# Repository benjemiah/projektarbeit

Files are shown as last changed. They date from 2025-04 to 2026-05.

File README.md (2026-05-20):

# projektarbeit

Git-Repo für die Projektarbeit des 6. Semesters

## Struktur

- **pcb**: KiCad-Projektdateien für die Platine des Retro-Terminals
  - **Gerber**: Gerber-Files der Platine
  - **eigenes.pretty**: Nicht-Standard Footprints/ Schaltzeichen für Bauteile
- **code**: Arduino-Code für die Atmega328P's des Retro-Terminals
- **presentation**
  - **website**: Website zur Präsentation des Projektseminars

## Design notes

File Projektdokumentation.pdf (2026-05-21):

## Projektdokumentation „Retro Terminal“ Ein Atmega328 Aufbau zur Verarbeitung von PS/2 Inputs und Ausgabe über VGA

Ein Projekt von Jule Jäger, Natalie Weigand und Benjamin Blaga 15.05.2026

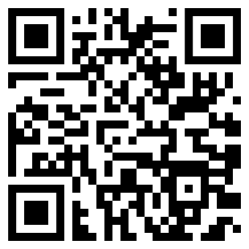
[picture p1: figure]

GitHub-Repo zum „Retro Terminal“

Ziel des Projekts:
Das Ziel des Projektes ist der Aufbau und die Inbetriebnahme einer eigens entworfenen Schaltung zum Einlesen, Auswerten und Ausgeben von PS/2 Inputs über VGA. Umgesetzt werden soll dies mithilfe von zwei ATmega328-P Mikrocontroller, vorgeladen mit dem Arduino Uno Bootloader. Dabei soll die Modularität für zukünftige Erweiterungen ermöglicht werden sowie ergänzende Funktionen wie z.B. ein Buzzer bereitgestellt werden.
Hauptfunktionen:
- Einlesen von Benutzerinput mithilfe einer Tastatur über den PS/2-Standard
- Ausgabe von eingelesenen Benutzerinput über monochromes VGA
- Ansteuerung eines Buzzers für akustische Funktionen
- Schaltungsaufbau ermöglicht einfaches Debugging bei Änderungsbedarf

Projektkomponenten:
- Platine
- Software

In dieser Dokumentation wird der Aufbau, die Systemkomponenten und die Inbetriebnahme erklärt.

## Platine

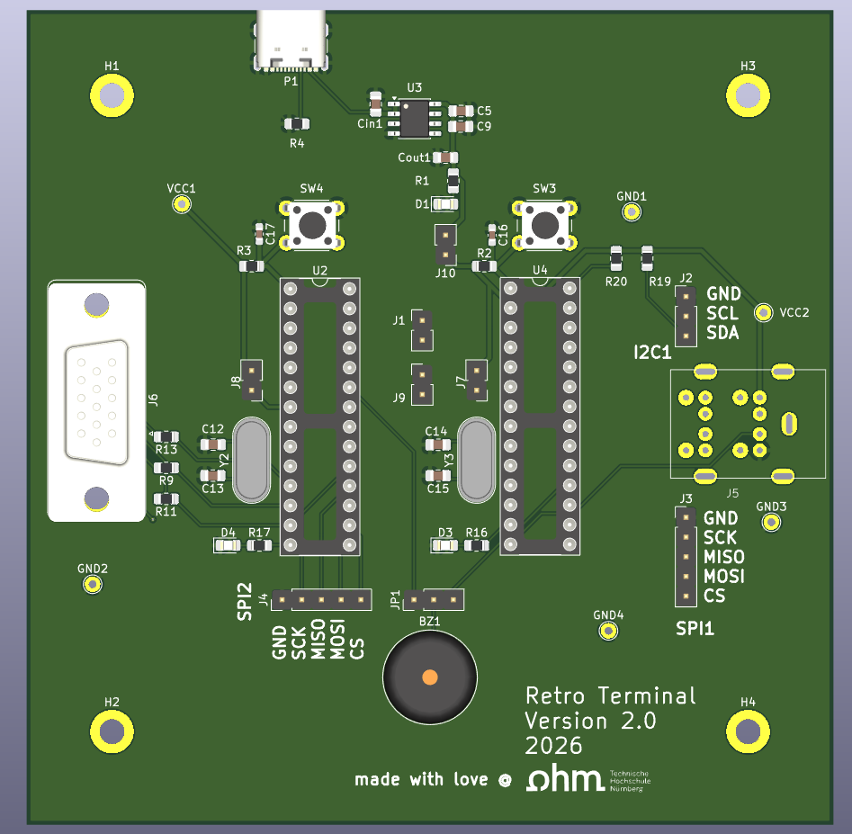
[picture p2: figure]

3D-Render der Platine, erstellt in KiCad (15.05.2026)
Stromversorgung

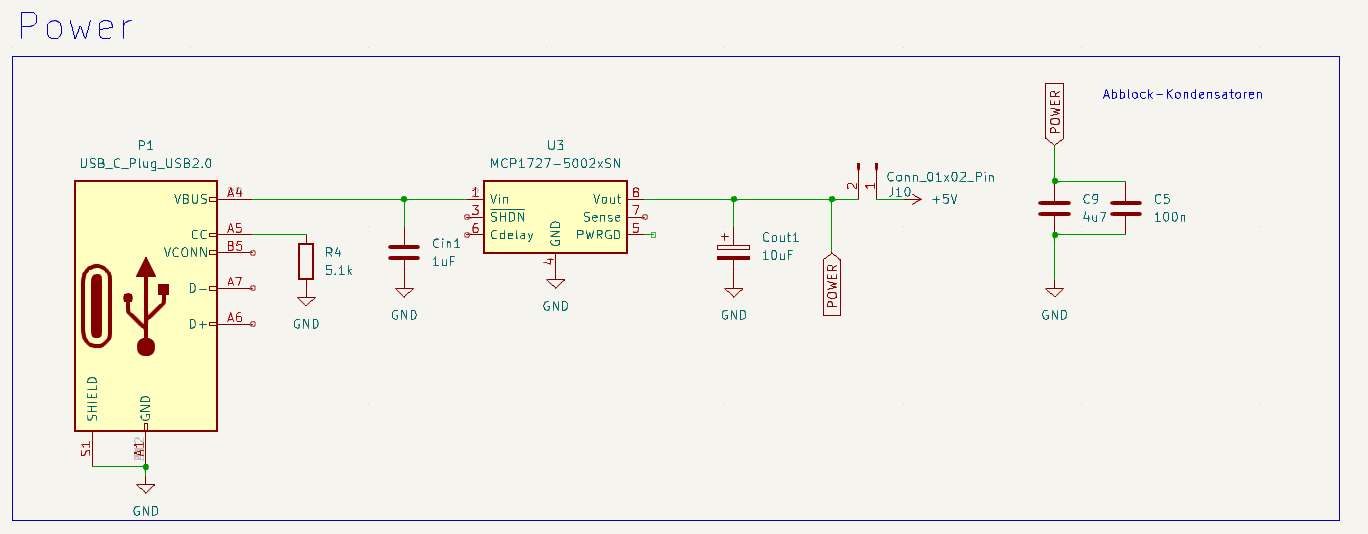
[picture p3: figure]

Die Platine wird versorgt mit einem USB-C Kabel über ein USB-C konformen Verbindungsstecker. Der Widerstand R4 vermittelt dem USB-C Host (Versorger) dass diese Platine ein Sink ist und Standard-USB-Spannung erwartet wird, in diesem Fall 5V. Weiterhin wird, um Überspannung zu verhindern ein LDO-Spannungsregler vom Typ MCP1727-5002 benutzt, um eine konstante Spannung von 5V zu garantieren sowie ein Maximalstrom von 1.5A. Zum Schutz der Mikrocontroller wurden Abblock-Kondensatoren platziert sowie Jumper-Pins, falls eine alternative Spannungsversorgung benötigt wird.

## Mikrocontroller

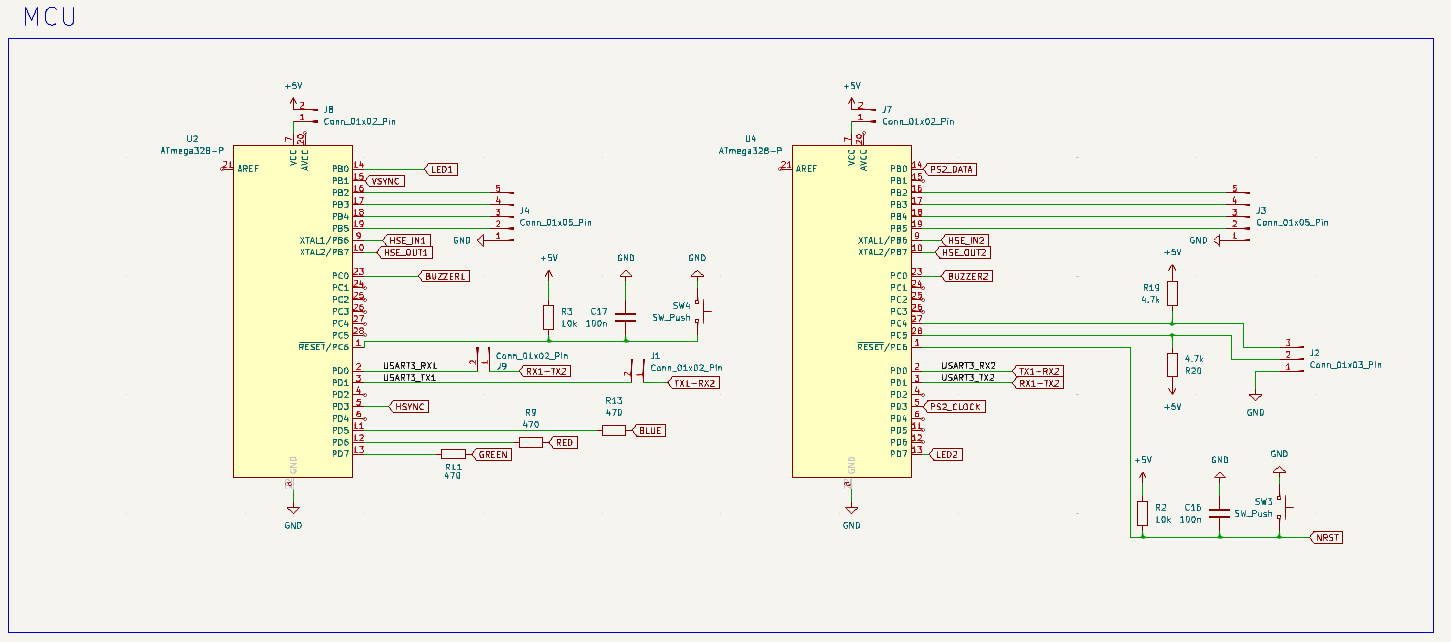
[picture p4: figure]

Die Platine utilisiert 2x Microchip ATmega328-P Mikrocontroller in der DIP-28 Bauform. Diese werden betrieben in einer Minimalausführung: Es werden lediglich Spannungsversorgung sowie Takt mithilfe von Standardquarzen (siehe unten) zugeführt. Um das Debugging zu erleichtern, haben die Mikrocontroller jeweils einzelne Reset-Knöpfe sowie Jumper-Pins zum optionalen Ausschalten der einzelnen Mikrocontroller.
Herausgeführt wurden die benötigten GPIO-Pins für die benötigten Funktionalitäten, namentlich:
- Verbindungen für VGA-Funktionalität (Pins gekennzeichnet mit „RED“, „GREEN“, „BLUE“, „VSYNC“, „HSYNC“)
- Verbindungen für PS/2-Funktionalität (Pins gekennzeichnet mit „PS2_CLOCK“, „PS2_DATA“)
- Verbindungen für die serielle Kommunikation zwischen den beiden ATmega328-P Mikrocontrollern (Pins gekennzeichnet mit „TX1-RX2“, „RX1-TX2“, „RX1-TX2“, „TX2-RX2“
- Verbindungen für Buzzer-Funktionalität (Pins gekennzeichnet mit „BUZZER1“, BUZZER2“)
- Verbindungen für serielle Schnittstellen für zukünftige Erweiterungen (Pins verbunden mit „J4“, „J3“ und „J2“
- Verbindungen für Status-LEDs (Pins gekennzeichnet mit „LED1“, „LED2“)

(Verbindungen zur allgemeinen Stromversorgung werden hier nicht berücksichtigt)

Es sind Jumper-Pins vorhanden um die bidirektionale Kommunikation über UART zwischen den Mikrocontrollern einzuschränken/ modifizieren zu können.
Beide Mikrocontroller sind in der Lage den Buzzer anzusteuern, falls benötigt.
„J2“ ist als I2C-Steckverbindung, „J3“ und „J4“ als SPI-Steckverbindungen vorgesehen.

## Diverse Systemkomponenten

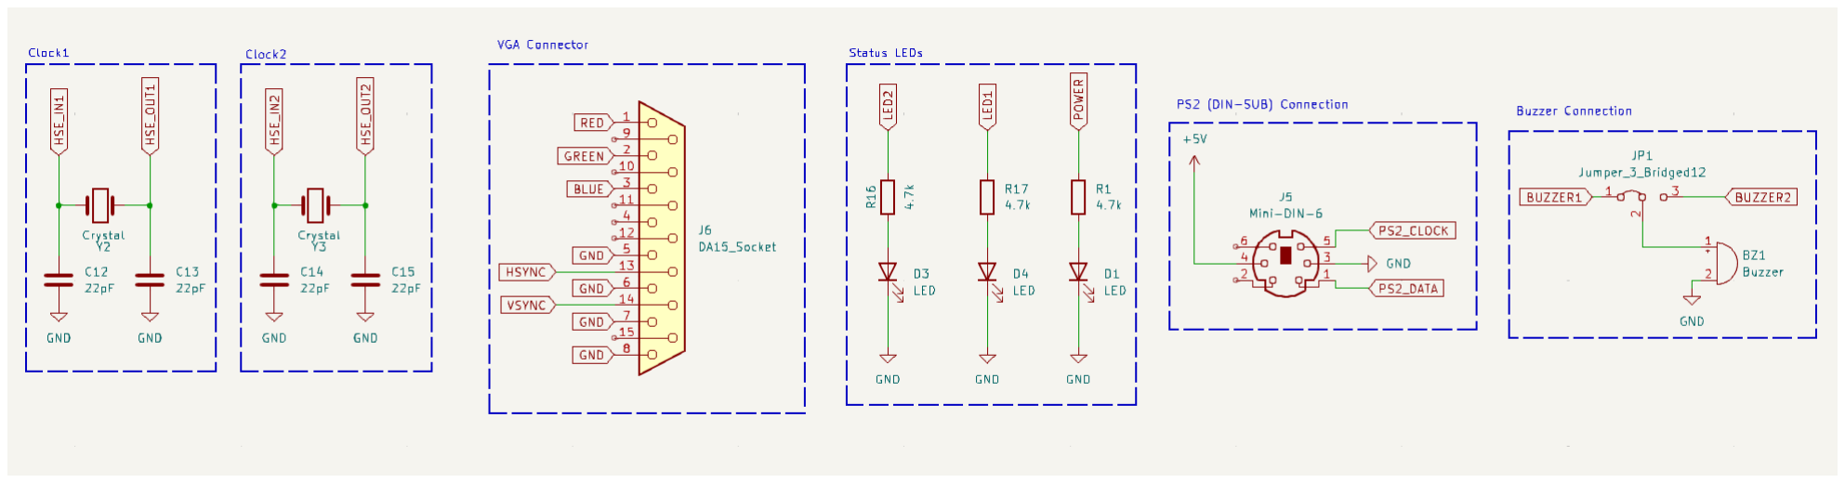
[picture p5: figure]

Zu den diversen Systemkomponenten zählen die Taktgeber in Form von Standardquarzen (sowie deren benötigte Keramikkondensatoren), die VGA-Steckverbindung, die Status-LEDs, die DIN6-SUB Steckverbindung für eine PS/2 Tastatur sowie der Buzzer.
Die Mikrocontroller haben jeweils eine Status-LED zum freien Ansteuern, weiterhin gibt es eine Status-LED zur Überwachung der Stromversorgung.
Der Buzzer kann über Jumper-Pins einem Mikrocontroller zur Ansteuerung zugewiesen werden.

## Mechanische Bauteile

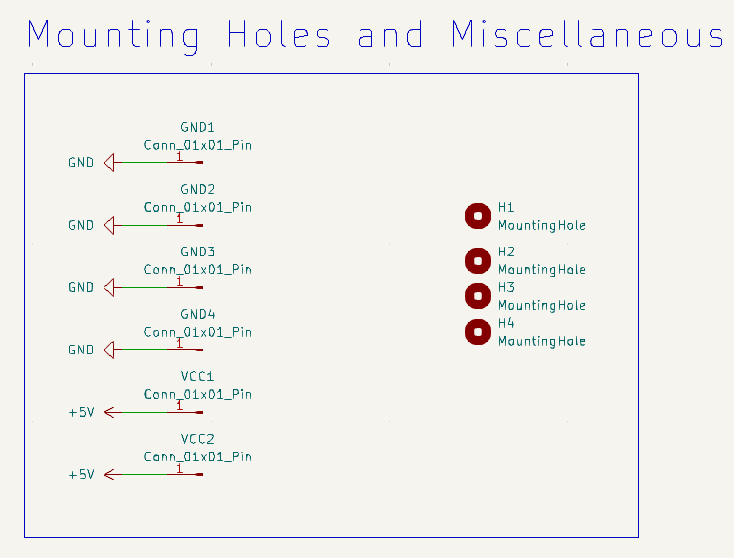
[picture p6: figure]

Die „Mounting Holes“ wurden platziert, um eine einfachere Montage zu ermöglichen. Weiterhin wurden, wie in der Praxis üblich, Vias bzw. Pins herausgeführt, um Betriebsspannungen messen zu können.

## Software

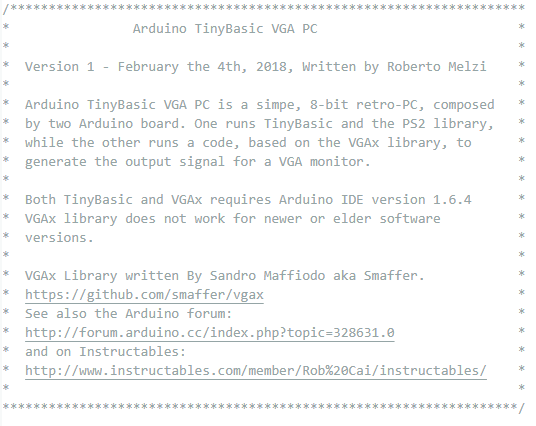
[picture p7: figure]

Projektbeschreibung „TinyBasic VGA PC“ von Roberto Melzi

Dieses Projekt benutzt eine abgeänderte Version des „Arduino TinyBasic VGA PC“- (https://www.instructables.com/Arduino-Basic-PC-With-VGA-Output/) Codes von Roberto Melzi. Dieses basiert wiederum auf der VGAx Library (https://github.com/smaffer/vgax) von Sandro Maffiodo, welches die Basis vieler Arduino-basierter VGA-Projekte darstellt. Diese Library stellt VGA-Funktionalität auf Hardware-Timer-Basis bereit und ermöglicht zusätzlich die Darstellung von Bildern. Aufgrund vom technischen Umfang einer Implementierung der VGA-Kommunikation benutzt dieses Projekt die VGAx-Schnittstelle bzw. eine modifizierte Version des „TinyBasic VGA PC“ Projektes zur Bereitstellung der erforderten Funktionalität.
Die benötigte Rechenlast zur Ausgabe von VGA-Videosignalen ist nicht besonders hoch, jedoch ist z.B. bei der Darstellung von Bildern ein Framebuffer notwendig. Dies füllt den beschränkt vorhandenen RAM des ATmega328P fast vollständig und schränkt die Größe des weiteren Codes ein. Deshalb wurde die PS/2 Kommunikation ausgelagert auf einen zweiten ATmega328P, um diesen zu entlasten. Somit wird der PS/2 Benutzerinput von einem ATmega328P eingelesen, verarbeitet und per „Serial.print()“ (UART) an den anderen ATmega328P gesendet.

Screenshot vom Code des VGA-ausgebenden Atmega328P

Dieser empfängt die gelesenen bytes über Serial.read() und gibt diese daraufhin aus.

## PS/2 Handling & BASIC-Interpreter

Der am PS/2 Port angeschlossene ATmega328P verarbeitet die eingelesenen Tastenschläge der PS/2-Tastatur sowie interpretiert Befehle, um Programmspeicher auf dem VGA-treibenden ATmega328P nicht zu vereinnahmen. Hierfür benutzt das geladene Programm die „PS2Keyboard“-Library die in der Arduino IDE über „Manage Libraries“ einzeln geladen werden kann. Grundsätzlich sind alle benötigten PS/2-Funktionen anhand dieser Library implementiert und benötigen lediglich die Konfiguration des Data-Pins sowie des IRQ-Pins.
Das geladene Programm beinhaltet eine Art BASIC-Interpreter:

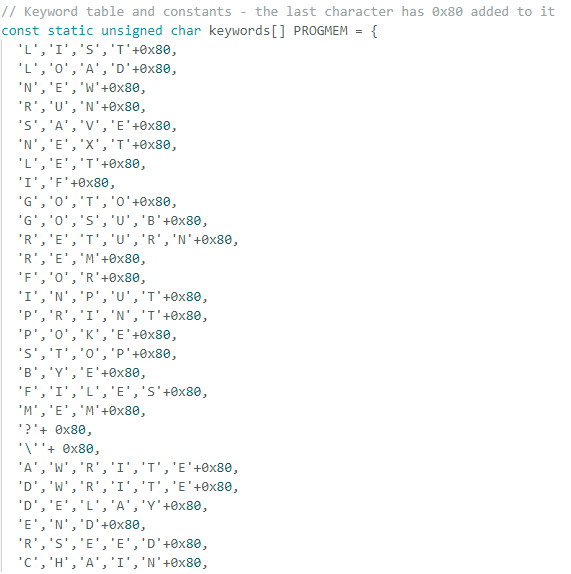
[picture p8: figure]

Screenshot des Codes mit den erwähnten Keywords

Diese können benutzt werden, um BASIC-artigen Code zu schreiben und lokal auszuführen. Weiterhin sind bestimmte Speicherbereiche für Variablen nach BASIC-Standard vorzufinden (gekennzeichnet als Variablen „A“ bis „Z“, intern gespeichert als short int).
Die unterstützen Rechenoperationen des Interpreters sind Addition („+“), Subtraktion („-“), Multiplikation („*“) und Division („/“). Weiterhin sind Vergleichsoperatoren vorzufinden: gleich („=“), ungleich („<>“ oder „!=“), kleiner („<“), größer („>“), kleiner gleich („<=“) und größer gleich („>=“).

Ebenfalls sind bereits primitive Funktionen implementiert.

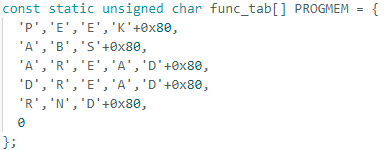
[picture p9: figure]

Zu erwähnen ist hierbei, dass z.B. die Funktion „PEEK()“, welche im BASIC-Standard zum Lesen von Speicherzellen gedacht ist, hierbei nur auf den beim Setup allokierten Speicher zugreift. Somit erfolgt lediglich ein Zugriff auf Programmspeicher und nicht ein Zugriff auf ein CPU-Register des ATmega328P. Die Funktionen „AREAD()“ und „DREAD()“ implementieren die Arduino-Funktionen „analogRead()“ und „digitalRead()“, welche jeweils das Einlesen von analogen und digitalen Werten möglich machen. Analog dazu sind ebenfalls die Funktionen „AWRITE()“ und „DWRITE()“ implementiert.

## Ablauf des Interpreters

setup()
Initialisiert:
- Serielle Schnitstelle
- (PS/2) Tastatur
- EEPROM (optional)
- SD-Karte (optional)
loop()
Hauptinterpreter:
- Speicher initialisieren
- BASIC-Eingabe lesen
- Zeilen speichern
- Befehle interpretieren
- Programme ausführen

Beispiel:

Screenshot eines Beispielprogramms

Der Interpreter reagiert auf Zahlen am Anfang einer Zeile als ein Marker für BASIC-Code. Somit wird der BASIC-Code direkt gespeichert und ohne Zahl am Zeilenanfang direkt ausgeführt

Erwartete Ausgabe des Codes

Funktionsablauf:

Der Interpreter erkennt „PRINT“ über scantable(keywords) und springt zu einem Funktionshandler. Dieser ruft die Funktion print_quoted_string() auf und der eingegebene String (welcher eingespeichert wurde) wird über outchar() ausgegeben, welches lediglich ein Wrapper für Serial.write() ist. Somit wird eingelesener Code/Input zuletzt über Serial.write() und somit über UART an den VGA-ATmega328P gesendet.
Durch Drücken von „Shift“ + „7“ kann die Farbe des CLI geändert werden (grün, rot, gelb). Durch „Ctrl“ + „C“ kann eine Endlosscheife unterbrochen werden.

Bekannte Probleme:

Aufgrund des begrenzten Speicherplatzes des ATmega328P kommt es schnell zu einem Überlauf. So können ohne Resets Befehle oft nicht verarbeitet werden (Benachrichtigung mit „What?“ oder „How?“). Ebenfalls werden die Tastenschläge nach US-Layout eingelesen, was bei nicht standardisierten PS/2 Tastaturen zu Problemen führen kann. Der Testaufbau erfolgte mit einer IBM-Model M Tastatur.

## Benutzung der Platine

Die Platine verfügt über einen USB-C Anschluss zur Stromversorgung. Programmiert werden die ATmega328P über ein Arduino UNO Board, da kein ISP vorhanden ist. Dazu werden die ATmega328P aus den jeweiligen Sockeln entfernt, in die Sockel auf dem Arduino UNO Board eingesteckt und wie gewohnt programmiert. Dazu sind im GitHub Repository zu diesem Projekt die „.ino“ Programme hinterlegt: Einmal „ps2_atmega328p“ sowie „vga_atmega328p“. Diese werden auf die dazugehörigen ATmega328P geladen. Danach ist das System startbereit. Die „POWER“ Status-LED kann beobachtet werden, um eine funktionierende Stromversorgung zu überprüfen. Zum Debuggen können die Jumper zur Stromversorgung der ATmega328P („J8“ und „J7“) einzeln entfernt werden, genauso wie die Verbindung zum Buzzer „BUZZER1“ („JP1“). Ebenfalls kann die UART-Kommunikation von bidirektional auf unidirektional (Master und Slave) durch Jumper („J1“, „J9“) umfunktioniert werden.
Wichtig hierbei ist anzumerken, dass die verwendeten ATmega328P den Arduino UNO Bootloader geladen haben müssen, damit dieses System funktioniert. Jedoch sind die meisten ATmega328P bereits damit vorprogrammiert ab Werk.
Die Farbe „BLUE“ für den VGA-Standard ist nicht angeschlossen, aufgrund der Auslegung auf einen monochromen Betrieb in der Library „VGAx“ auf der das TinyBasic Projekt basiert. Jedoch kann. falls gewünscht, der Pin überbrückt werden und die Library umprogrammiert werden, da ein geeigneter Pin an PORTD hierfür ausgelegt wurde.
Dieses System kann erweitert werden mit einem EEPROM und/oder SPI und I2C Modulen. Jedoch muss zur Erweiterung mit serieller Kommunikation das Timing berücksichtigt werden. Hierzu bitte die Hinweise im „VGAx“ GitHub Repo (https://github.com/smaffer/vgax) berücksichtigen, falls die Erweiterungen auf dem „VGA“ Atmega328P erfolgen.

## Implementierung auf STM32-Basis

Grundsätzlich lässt sich dieses Projekt mit derselben Funktionalität auch auf einem STM32 implementieren. VGA-Libraries auf STM32-Basis sind vorhanden, jedoch sind die meisten bereits veraltet und nicht für die im MCT-Labor zu findenden STM32-Geräte vorgesehen. Somit wäre ein Port auf beispielsweise die STM32L4-Reihe notwendig.
Zu beachten ist, dass die „Totzeiten“, also Front- und Backporch, essenziell sind, um Fragmentierungen im Signal zu verhindern. Dafür müssen Timer aneinandergekettet werden; Softwaretimer kommen aufgrund der erforderlichen Synchronität nicht infrage. Eine Implementierung ist jedoch auch ohne DMA möglich.
Der BASIC-Interpreter kann von der Logik her übernommen werden, müsste jedoch auf STM32-Cube IDE konformen Code umgeschrieben werden.

Folgend sind Ressourcen gelistet, die den Prozess näher beschreiben:

https://mikrocontroller.bplaced.net/wordpress/stm32f4/komplette-library-liste-stm32f4/35-vga_screen-library-stm32f4/ (https://mikrocontroller.bplaced.net/wordpress/stm32f4/komplette-library-liste-stm32f4/35-vga_screen-library-stm32f4/)
https://github.com/RoCorbera/BlueVGA
https://martin.hinner.info/vga/timing.htmlhttps://github.com/MR-Addict/STM32-HAL-PS2-Library

Quellen:
https://www.instructables.com/Arduino-Basic-PC-With-VGA-Output/ (abgerufen am 20.05.2026) https://github.com/smaffer/vgax (abgerufen am 20.05.2026) https://www.circuito.io/blog/arduino-uno-pinout/ (abgerufen am 20.05.2026) https://github.com/benjemiah/projektarbeit (abgerufen am 20.05.2026)

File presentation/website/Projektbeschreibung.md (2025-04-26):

## Projektbeschreibung

Dieses Projekt stellt eine einfache HTML-Seite mit einem Login-Formular dar. Der Benutzer kann seine Anmeldedaten eingeben (Loginname und Passwort). Bei korrektem Login werden sie auf eine andere Seite weitergeleitet.

## Hauptfunktionen

- Benutzer können ihre Anmeldedaten eingeben.

- Ein "Test-Login" ist implementiert (Benutzername: testuser, Passwort: testpass).

- Nach erfolgreichem Login erfolgt eine Weiterleitung zu einer neuen Seite (seite.html), nach einer kurzen Verzögerung von 5 Sekunden.

## Zielgruppe

Diese Demo ist für Entwickler gedacht, die ein einfaches Login-Formular implementieren möchten.

## Verwendete Sprache/Skripte

HTML

- HTML: Die Struktur der Seite, einschließlich des Login-Formulars.

- CSS: Grundlegendes Styling der Login-Seite.

- JavaScript: Überprüft die Eingabedaten und steuert die Weiterleitung zur nächsten Seite.

## Projektstruktur

├── index.html        # Die Hauptdatei mit der Weiterleitung zum Login Formular
└── andereSeite.html  # Login Formular
└── seite.html        # Seite nach erfolgreichem Login

## Dateien im Detail

- index.html

Enthält eine Website gefüllt mit Lorem-Ipsum Text sowie einen Button über den man Zugriff erhält auf das Login Formular

- andereSeite.html

Enthält das Login Formular, bei dem sich der Benutzer mit einem Passwort und einem Benutzernamen anmelden kann

- seite.html

Enthält Text als visuelle Bestätigung eines erfolgreichen Logins!

## Installation/Ausführung

Step 1: Git-Repo klonen : git@github.com:benjemiah/projektarbeit.git
Step 2: index.html im Browser aufrufen
Step 3: Name und Passwort eingeben

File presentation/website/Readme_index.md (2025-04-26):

### Code

Es folgt eine detaillierte Beschreibung des Codes den man in den Dateien des Projekts findet. Nähere Beschreibungen der Projektstruktur, der Zielsetzung und der verwendeten Sprachen sind in der Projektbeschreibung.md zu finden!

## Allgemeins zur Datei index.html

- Dateiname :  index.html
- Sprache   :  HTML5
- Ziel      :  Eine Simple Landing Page mit Weiterleitung an ein Login-Formular

# Struktur und Funktionsweise

<!DOCTYPE html>                         # Das ist der Standard HTML Header zur Identifizierung der Datei
<html lang="en">                        # globaler Bezeichner für die Sprache
<head>                                  
<title>W3.CSS Template</title>          # Titel der Website
<meta charset="UTF-8">                  # Definierung der benutzten Zeichen

# Dependencies, müssen eingebunden werden für Grafiken und Fonts

<meta name="viewport" content="width=device-width, initial-scale=1">
<link rel="stylesheet" href="https://www.w3schools.com/w3css/5/w3.css">
<link rel="stylesheet" href="https://fonts.googleapis.com/css?family=Lato">
<link rel="stylesheet" href="https://fonts.googleapis.com/css?family=Montserrat">
<link rel="stylesheet" href="https://cdnjs.cloudflare.com/ajax/libs/font-awesome/4.7.0/css/font-awesome.min.css">
# Beschreibung der Schriftarten und ihrer Styles
<style>
body,h1,h2,h3,h4,h5,h6 {font-family: "Lato", sans-serif}
.w3-bar,h1,button {font-family: "Montserrat", sans-serif}
.fa-anchor,.fa-coffee {font-size:200px}
</style>
</head>

# Navbar 

<!-- Navbar -->
<div class="w3-top">  # Fixierte Navbar am oberen Bildschirmrand

  <div class="w3-bar w3-red w3-card w3-left-align w3-large">  # Hauptleiste in Rot mit Schatteneffekt und linksbündigen Elementen

    <a class="w3-bar-item w3-button w3-hide-medium w3-hide-large w3-right w3-padding-large w3-hover-white w3-large w3-red"
       href="javascript:void(0);"
       onclick="myFunction()"
       title="Toggle Navigation Menu">
       <i class="fa fa-bars"></i>
    </a>  # Hamburger-Menü-Icon für kleine Bildschirme, aktiviert per JavaScript die mobile Navigation

    <a href="#" class="w3-bar-item w3-button w3-padding-large w3-white">Home</a>  # Aktiver Home-Link mit weißem Hintergrund

  </div>

    # Verstecktes mobiles Navigationsmenü, wird über JavaScript angezeigt
</div>

# Body

<!-- Header -->
<header class="w3-container w3-red w3-center" style="padding:128px 16px">  # Großer, roter Header-Bereich mit zentriertem Text und großzügigem Innenabstand
  <h1 class="w3-margin w3-jumbo">Hier könnte ihre Werbung stehen!</h1>      # Hauptüberschrift mit großem Schriftstil
  <p class="w3-xlarge">Ich brauche 1 Million Euro</p>                      # Untertitel im XL-Stil

  <!-- Der Button ist jetzt ein Link -->
  <a href="andereSeite.html">                                              # Link zur Weiterleitung auf eine andere HTML-Seite
    <button class="w3-button w3-black w3-padding-large w3-large w3-margin-top">Get Started</button>  # Schwarzer, großer Button
  </a>
</header>

<!-- First Grid -->
<div class="w3-row-padding w3-padding-64 w3-container">  # Erster Inhaltsblock mit Abstand außen (padding)
  <div class="w3-content">                              # Zentrierter Container für Inhalt mit fixer Maximalbreite
    <div class="w3-twothird">                           # Zweidrittel der Breite für Text
      <h1>Lorem Ipsum</h1>                              # Abschnittsüberschrift
      <h5 class="w3-padding-32">Lorem ipsum ...</h5>    # Einführungstext mit Abstand innen
      <p class="w3-text-grey">Lorem ipsum ...</p>       # Grauer Fließtext mit Blindtext (Platzhalter)
    </div>

    <div class="w3-third w3-center">                    # Ein Drittel der Breite für Symbol
      <i class="fa fa-anchor w3-padding-64 w3-text-red"></i>  # Ankersymbol aus Font Awesome, rot und mit Innenabstand
    </div>
  </div>
</div>

<!-- Second Grid -->
<div class="w3-row-padding w3-light-grey w3-padding-64 w3-container">  # Zweiter Inhaltsblock mit hellem Hintergrund
  <div class="w3-content">                                             # Gleiche Struktur wie oben
    <div class="w3-third w3-center">                                   # Symbol auf der linken Seite
      <i class="fa fa-coffee w3-padding-64 w3-text-red w3-margin-right"></i>  # Kaffeesymbol mit roter Farbe und rechtem Außenabstand
    </div>

    <div class="w3-twothird">                                          # Zweidrittel des Bereichs für Text
      <h1>Lorem Ipsum</h1>                                             # Abschnittsüberschrift
      <h5 class="w3-padding-32">Lorem ipsum ...</h5>                   # Einführungstext
      <p class="w3-text-grey">Lorem ipsum ...</p>                      # Grauer Fließtext mit Platzhaltertext
    </div>
  </div>
</div>

<div class="w3-container w3-black w3-center w3-opacity w3-padding-64">  # Schwarzer Bereich mit Transparenz und zentriertem Text
  <h1 class="w3-margin w3-xlarge">Quote of the day: live life</h1>     # Zitat im XL-Stil als Abschluss
</div>

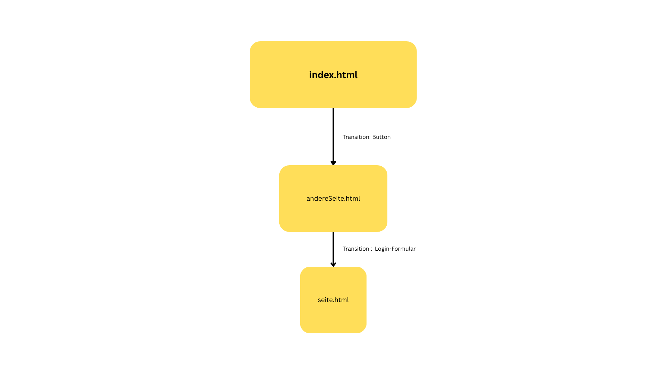
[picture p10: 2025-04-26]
presentation/website/index.html.png

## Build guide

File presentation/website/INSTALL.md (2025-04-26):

### INSTALLATION

## Zur Installation und Aufsetzung dieses Projektes sind folgende Schritte notwendig:

## Step 1:
Git Repo auf lokalen Rechner klonen
# HTTPS:
https://github.com/benjemiah/projektarbeit.git

# SSH:
git@github.com:benjemiah/projektarbeit.git

## Step 2:

index.html im eigenen Browser aufrufen

http://localhost/index.html 

## Step 3:

Nach dem sich die Landing-Page geöffnet hat, auf den Button "Get Started" klicken und in das Login-Formular übergehen

## Step 4:

Benutzername testuser und Passwort testpass eingeben

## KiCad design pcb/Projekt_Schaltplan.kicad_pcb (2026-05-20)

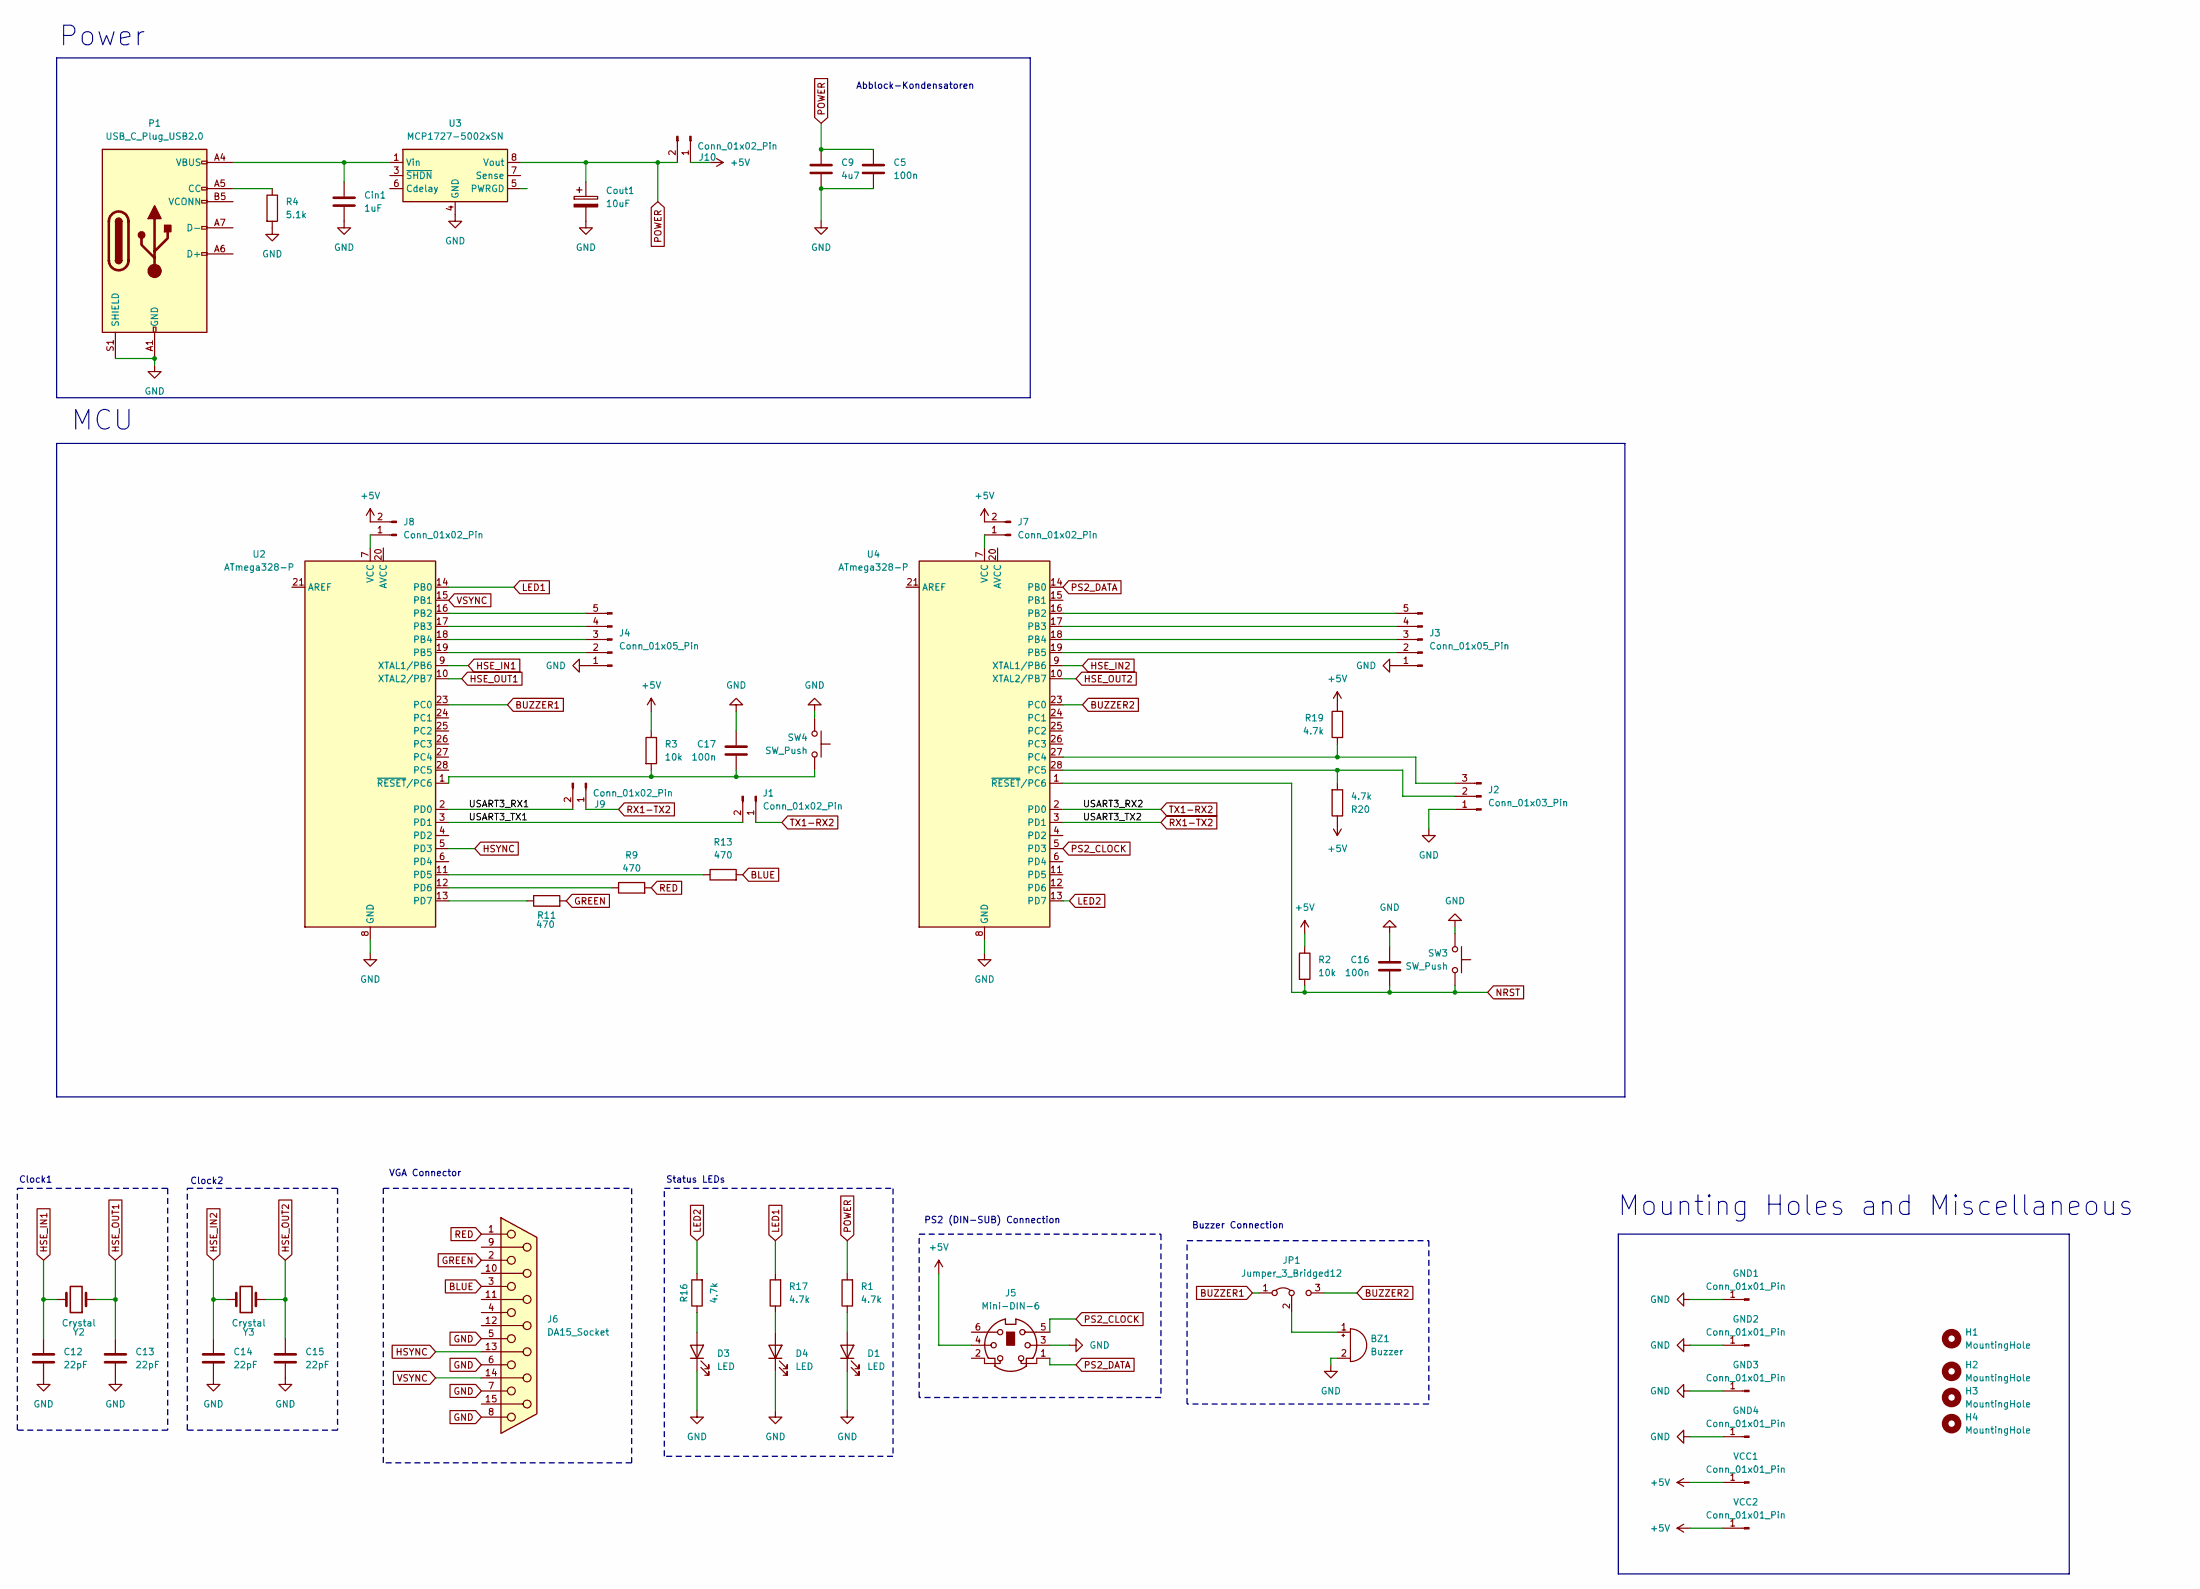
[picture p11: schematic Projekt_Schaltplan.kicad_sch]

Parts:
BZ1: Buzzer; Buzzer_12x9.5RM7.6
C5: 100n; C_0805_2012Metric_Pad1.18x1.45mm_HandSolder
C9: 4u7; C_0805_2012Metric_Pad1.18x1.45mm_HandSolder
C12, C13, C14, C15: 22pF; C_0805_2012Metric_Pad1.18x1.45mm_HandSolder
C16, C17: 100n; C_0603_1608Metric_Pad1.08x0.95mm_HandSolder
Cin1: 1uF; C_0805_2012Metric_Pad1.18x1.45mm_HandSolder
Cout1: 10uF; C_0805_2012Metric_Pad1.18x1.45mm_HandSolder
D1, D3, D4: LED; LED_0805_2012Metric_Pad1.15x1.40mm_HandSolder
GND1, GND2, GND3, GND4: Conn_01x01_Pin; TestPoint_THTPad_D2.0mm_Drill1.0mm
H1, H2, H3, H4: MountingHole; MountingHole_3.2mm_M3_DIN965_Pad
J1, J7, J8, J9, J10: Conn_01x02_Pin; PinHeader_1x02_P2.54mm_Vertical
J2: Conn_01x03_Pin; PinHeader_1x03_P2.54mm_Vertical
J3, J4: Conn_01x05_Pin; PinHeader_1x05_P2.54mm_Vertical
J5: Mini-DIN-6; ps2-buchse-6pin
J6: DA15_Socket; DSUB-15-HD_Socket_Vertical_P2.29x1.98mm_MountingHoles
JP1: Jumper_3_Bridged12; PinHeader_1x03_P2.54mm_Vertical
P1: USB_C_Plug_USB2.0; USB_C_Receptacle_GCT_USB4105-xx-A_16P_TopMnt_Horizontal
R1, R16, R17, R19, R20: 4.7k; R_0805_2012Metric_Pad1.20x1.40mm_HandSolder
R2, R3: 10k; R_0805_2012Metric_Pad1.20x1.40mm_HandSolder
R4: 5.1k; R_0805_2012Metric_Pad1.20x1.40mm_HandSolder
R9, R11, R13: 470; R_0805_2012Metric_Pad1.20x1.40mm_HandSolder
SW3, SW4: SW_Push; SW_PUSH_6mm
U2, U4: ATmega328-P; DIP-28_W7.62mm_Socket
U3: MCP1727-5002xSN; SOIC-8_3.9x4.9mm_P1.27mm
VCC1, VCC2: Conn_01x01_Pin; TestPoint_THTPad_D2.0mm_Drill1.0mm
Y2, Y3: Crystal; Crystal_HC49-U_Vertical

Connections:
+5V: J5.4, J7.2, J8.2, J10.1, R2.1, R3.1, R19.1, R20.1, VCC1.1, VCC2.1
/USART3_RX1: J9.2, U2.2 (PD0)
/USART3_TX1: J1.2, U2.3 (PD1)
BLUE: J6.3, R13.2
BUZZER1: JP1.1 (A), U2.23 (PC0)
BUZZER2: JP1.3 (B), U4.23 (PC0)
GND: BZ1.2 (-), C5.2, C9.2, C12.2, C13.2, C14.2, C15.2, C16.1, C17.1, Cin1.2, Cout1.2, D1.1 (K), D3.1 (K), D4.1 (K), GND1.1, GND2.1, GND3.1, GND4.1, J2.1, J3.1, J4.1, J5.3, J6.5, J6.6, J6.7, J6.8, P1.A1 (GND), P1.A12 (GND), P1.B1 (GND), P1.B12 (GND), P1.S1 (SHIELD), R4.2, SW3.2, SW4.2, U2.8 (GND), U2.22 (GND), U3.4 (GND), U4.8 (GND), U4.22 (GND)
GREEN: J6.2, R11.2
HSE_IN1: C12.1, U2.9 (XTAL1/PB6), Y2.2
HSE_IN2: C14.1, U4.9 (XTAL1/PB6), Y3.2
HSE_OUT1: C13.1, U2.10 (XTAL2/PB7), Y2.1
HSE_OUT2: C15.1, U4.10 (XTAL2/PB7), Y3.1
HSYNC: J6.13, U2.5 (PD3)
LED1: R17.2, U2.14 (PB0)
LED2: R16.2, U4.13 (PD7)
NRST: C16.2, R2.2, SW3.1, U4.1 (~RESET/PC6)
unnamed: BZ1.1 (+), JP1.2 (C)
unnamed: Cin1.1, P1.A4 (VBUS), P1.A9 (VBUS), P1.B4 (VBUS), P1.B9 (VBUS), U3.1 (Vin), U3.2 (Vin)
unnamed: D1.2 (A), R1.1
unnamed: D3.2 (A), R16.1
unnamed: D4.2 (A), R17.1
unnamed: J2.2, R20.2, U4.28 (PC5)
unnamed: J2.3, R19.2, U4.27 (PC4)
unnamed: J3.2, U4.19 (PB5)
unnamed: J3.3, U4.18 (PB4)
unnamed: J3.4, U4.17 (PB3)
unnamed: J3.5, U4.16 (PB2)
unnamed: J4.2, U2.19 (PB5)
unnamed: J4.3, U2.18 (PB4)
unnamed: J4.4, U2.17 (PB3)
unnamed: J4.5, U2.16 (PB2)
unnamed: J7.1, U4.7 (VCC)
unnamed: J8.1, U2.7 (VCC)
unnamed: P1.A5 (CC), R4.1
unnamed: R13.1, U2.11 (PD5)
unnamed: R9.1, U2.12 (PD6)
unnamed: R11.1, U2.13 (PD7)
unnamed: C17.2, R3.2, SW4.1, U2.1 (~RESET/PC6)
POWER: C5.1, C9.1, Cout1.1, J10.2, R1.2, U3.8 (Vout)
PS2_CLOCK: J5.5, U4.5 (PD3)
PS2_DATA: J5.1, U4.14 (PB0)
RED: J6.1, R9.2
RX1-TX2: J9.1, U4.3 (PD1)
TX1-RX2: J1.1, U4.2 (PD0)
VSYNC: J6.14, U2.15 (PB1)

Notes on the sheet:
Power
Clock1
PS2 (DIN-SUB) Connection
Clock2
Abblock-Kondensatoren
Buzzer Connection
MCU
Mounting Holes and Miscellaneous
Status LEDs
VGA Connector

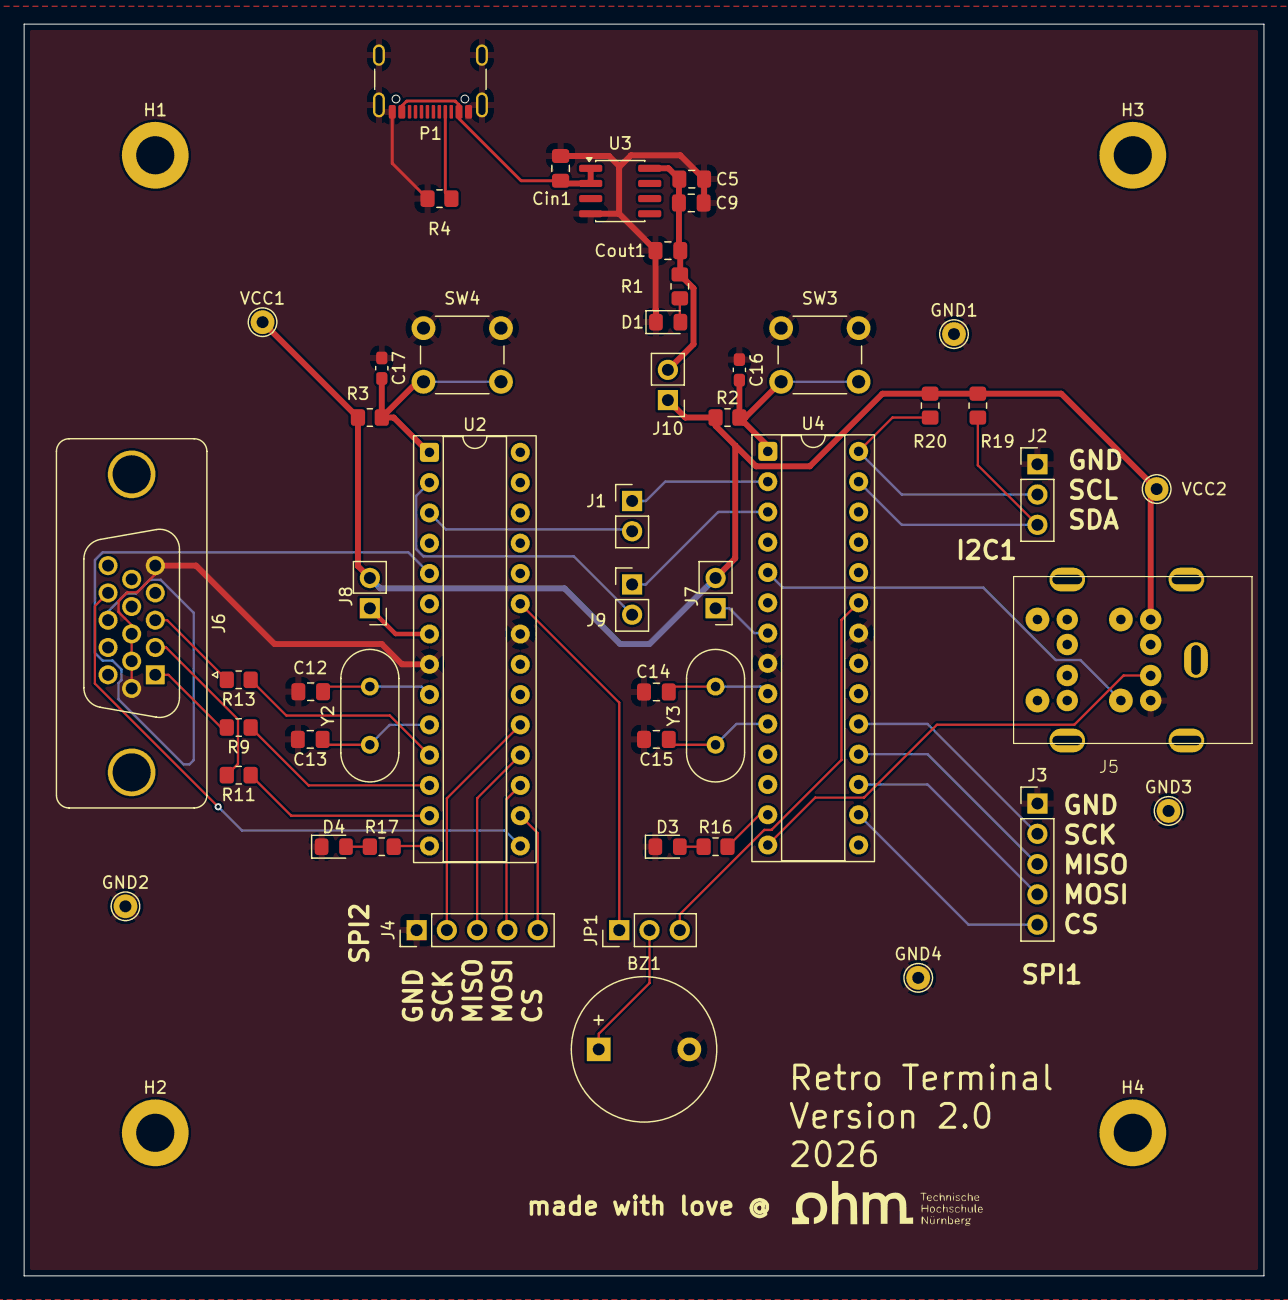
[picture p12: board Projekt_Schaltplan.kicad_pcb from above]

Board: 2 copper layers, 104.0 x 105.0 mm, 54 parts (0 on the bottom side), 45 nets.

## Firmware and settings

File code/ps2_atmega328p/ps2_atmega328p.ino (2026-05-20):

//////////////////////////////////////////////////////////////////////////
//             TinyBasic Plus + PS2 keyboard                            //
//   a modified version for the "RetroTerminal"                         //
//   modified by blagabe88296@th-nuernberg.de                           // 
//////////////////////////////////////////////////////////////////////////
//
// Authors: Mike Field <hamster@snap.net.nz>
//	    Scott Lawrence <yorgle@gmail.com>
//          Brian O'Dell <megamemnon@megamemnon.com>
//
//      Connections: 
//      Keyboard Data to Arduino pin 8;
//      Keyboard IRQ (clock) to Arduino pin 3;

#define kVersion "v0.14"


char eliminateCompileErrors = 1;  // fix to suppress arduino build errors

// hack to let makefiles work with this file unchanged
#ifdef FORCE_DESKTOP 
#undef ARDUINO
#include "desktop.h"
#else
#define ARDUINO 1
#endif


////////////////////////////////////////////////////////////////////////////////
// Feature option configuration...

// This enables LOAD, SAVE, FILES commands through the Arduino SD Library
// it adds 9k of usage as well.
//#define ENABLE_FILEIO 1
#undef ENABLE_FILEIO

// this turns on "autorun".  if there's FileIO, and a file "autorun.bas",
// then it will load it and run it when starting up
//#define ENABLE_AUTORUN 1
#undef ENABLE_AUTORUN
// and this is the file that gets run
#define kAutorunFilename  "autorun.bas"

// this is the alternate autorun.  Autorun the program in the eeprom.
// it will load whatever is in the EEProm and run it
#define ENABLE_EAUTORUN 1
//#undef ENABLE_EAUTORUN

// this will enable the "TONE", "NOTONE" command using a piezo
// element on the specified pin.  Wire the red/positive/piezo to the kPiezoPin,
// and the black/negative/metal disc to ground.
// it adds 1.5k of usage as well.
//#define ENABLE_TONES 1
#undef ENABLE_TONES
#define kPiezoPin 5

// we can use the EEProm to store a program during powerdown.  This is 
// 1kbyte on the '328, and 512 bytes on the '168.  Enabling this here will
// allow for this funcitonality to work.  Note that this only works on AVR
// arduino.  Disable it for DUE/other devices.
#define ENABLE_EEPROM 1
//#undef ENABLE_EEPROM

// Sometimes, we connect with a slower device as the console.
// Set your console D0/D1 baud rate here (9600 baud default)
//#define kConsoleBaud 9600
#define kConsoleBaud 4800 //-----------------------------------------------------------------------------------------------------------------------------------------------------------------------

////////////////////////////////////////////////////////////////////////////////
#ifdef ARDUINO
#ifndef RAMEND
// okay, this is a hack for now
// if we're in here, we're a DUE probably (ARM instead of AVR)

#define RAMEND 4096-1

// turn off EEProm
#undef ENABLE_EEPROM
#undef ENABLE_TONES

#else
// we're an AVR!

// we're moving our data strings into progmem
#include <avr/pgmspace.h>
#endif

// includes, and settings for Arduino-specific functionality
#ifdef ENABLE_EEPROM
#include <EEPROM.h>  /* NOTE: case sensitive */
int eepos = 0;
#endif

//---------------------------------------------------------------------------------------------------------------------------------------------------
#include <PS2Keyboard.h>
const int DataPin = 8;
const int IRQpin =  3;
PS2Keyboard keyboard;
//-------------------------------------------------------------------------------------------------------------------------------------------------------
  
  

#ifdef ENABLE_FILEIO
#include <SD.h>
#include <SPI.h> /* needed as of 1.5 beta */

// Arduino-specific configuration
// set this to the card select for your SD shield
#define kSD_CS 10

#define kSD_Fail  0
#define kSD_OK    1

File fp;
#endif

// set up our RAM buffer size for program and user input
// NOTE: This number will have to change if you include other libraries.
#ifdef ARDUINO
#ifdef ENABLE_FILEIO
#define kRamFileIO (1030) /* approximate */
#else
#define kRamFileIO (0)
#endif
#ifdef ENABLE_TONES
#define kRamTones (40)
#else
#define kRamTones (0)
#endif
#endif /* ARDUINO */
#define kRamSize  (RAMEND - 1160 - kRamFileIO - kRamTones) 

#ifndef ARDUINO
// Not arduino setup
#include <stdio.h>
#include <stdlib.h>
#undef ENABLE_TONES

// size of our program ram
#define kRamSize   4096 /* arbitrary */

#ifdef ENABLE_FILEIO
FILE * fp;
#endif
#endif

#ifdef ENABLE_FILEIO
// functions defined elsehwere
void cmd_Files( void );
#endif

////////////////////

#ifndef boolean 
#define boolean int
#define true 1
#define false 0
#endif
#endif

#ifndef byte
typedef unsigned char byte;
#endif

// some catches for AVR based text string stuff...
#ifndef PROGMEM
#define PROGMEM
#endif
#ifndef pgm_read_byte
#define pgm_read_byte( A ) *(A)
#endif

////////////////////

#ifdef ENABLE_FILEIO
unsigned char * filenameWord(void);
static boolean sd_is_initialized = false;
#endif

boolean inhibitOutput = false;
static boolean runAfterLoad = false;
static boolean triggerRun = false;

// these will select, at runtime, where IO happens through for load/save
enum {
  kStreamSerial = 0,
  kStreamEEProm,
  kStreamFile
};
static unsigned char inStream = kStreamSerial;
static unsigned char outStream = kStreamSerial;


////////////////////////////////////////////////////////////////////////////////
// ASCII Characters
#define CR	'\r'
#define NL	'\n'
#define LF      0x0a
#define TAB	'\t'
#define BELL	'\b'
#define SPACE   ' '
#define SQUOTE  '\''
#define DQUOTE  '\"'
#define CTRLC	0x03
#define CTRLH	0x08
#define CTRLS	0x13
#define CTRLX	0x18

typedef short unsigned LINENUM;
#ifdef ARDUINO
#define ECHO_CHARS 1
#else
#define ECHO_CHARS 0
#endif


static unsigned char program[kRamSize];
static const char *  sentinel = "HELLO";
static unsigned char *txtpos,*list_line, *tmptxtpos;
static unsigned char expression_error;
static unsigned char *tempsp;

/***********************************************************/
// Keyword table and constants - the last character has 0x80 added to it
const static unsigned char keywords[] PROGMEM = {
  'L','I','S','T'+0x80,
  'L','O','A','D'+0x80,
  'N','E','W'+0x80,
  'R','U','N'+0x80,
  'S','A','V','E'+0x80,
  'N','E','X','T'+0x80,
  'L','E','T'+0x80,
  'I','F'+0x80,
  'G','O','T','O'+0x80,
  'G','O','S','U','B'+0x80,
  'R','E','T','U','R','N'+0x80,
  'R','E','M'+0x80,
  'F','O','R'+0x80,
  'I','N','P','U','T'+0x80,
  'P','R','I','N','T'+0x80,
  'P','O','K','E'+0x80,
  'S','T','O','P'+0x80,
  'B','Y','E'+0x80,
  'F','I','L','E','S'+0x80,
  'M','E','M'+0x80,
  '?'+ 0x80,
  '\''+ 0x80,
  'A','W','R','I','T','E'+0x80,
  'D','W','R','I','T','E'+0x80,
  'D','E','L','A','Y'+0x80,
  'E','N','D'+0x80,
  'R','S','E','E','D'+0x80,
  'C','H','A','I','N'+0x80,
#ifdef ENABLE_TONES
  'T','O','N','E','W'+0x80,
  'T','O','N','E'+0x80,
  'N','O','T','O','N','E'+0x80,
#endif
#ifdef ARDUINO
#ifdef ENABLE_EEPROM
  'E','C','H','A','I','N'+0x80,
  'E','L','I','S','T'+0x80,
  'E','L','O','A','D'+0x80,
  'E','F','O','R','M','A','T'+0x80,
  'E','S','A','V','E'+0x80,
#endif
#endif
  0
};

// by moving the command list to an enum, we can easily remove sections 
// above and below simultaneously to selectively obliterate functionality.
enum {
  KW_LIST = 0,
  KW_LOAD, KW_NEW, KW_RUN, KW_SAVE,
  KW_NEXT, KW_LET, KW_IF,
  KW_GOTO, KW_GOSUB, KW_RETURN,
  KW_REM,
  KW_FOR,
  KW_INPUT, KW_PRINT,
  KW_POKE,
  KW_STOP, KW_BYE,
  KW_FILES,
  KW_MEM,
  KW_QMARK, KW_QUOTE,
  KW_AWRITE, KW_DWRITE,
  KW_DELAY,
  KW_END,
  KW_RSEED,
  KW_CHAIN,
#ifdef ENABLE_TONES
  KW_TONEW, KW_TONE, KW_NOTONE,
#endif
#ifdef ARDUINO
#ifdef ENABLE_EEPROM
  KW_ECHAIN, KW_ELIST, KW_ELOAD, KW_EFORMAT, KW_ESAVE, 
#endif
#endif
  KW_DEFAULT /* always the final one*/
};

struct stack_for_frame {
  char frame_type;
  char for_var;
  short int terminal;
  short int step;
  unsigned char *current_line;
  unsigned char *txtpos;
};

struct stack_gosub_frame {
  char frame_type;
  unsigned char *current_line;
  unsigned char *txtpos;
};

const static unsigned char func_tab[] PROGMEM = {
  'P','E','E','K'+0x80,
  'A','B','S'+0x80,
  'A','R','E','A','D'+0x80,
  'D','R','E','A','D'+0x80,
  'R','N','D'+0x80,
  0
};
#define FUNC_PEEK    0
#define FUNC_ABS     1
#define FUNC_AREAD   2
#define FUNC_DREAD   3
#define FUNC_RND     4
#define FUNC_UNKNOWN 5

const static unsigned char to_tab[] PROGMEM = {
  'T','O'+0x80,
  0
};

const static unsigned char step_tab[] PROGMEM = {
  'S','T','E','P'+0x80,
  0
};

const static unsigned char relop_tab[] PROGMEM = {
  '>','='+0x80,
  '<','>'+0x80,
  '>'+0x80,
  '='+0x80,
  '<','='+0x80,
  '<'+0x80,
  '!','='+0x80,
  0
};

#define RELOP_GE		0
#define RELOP_NE		1
#define RELOP_GT		2
#define RELOP_EQ		3
#define RELOP_LE		4
#define RELOP_LT		5
#define RELOP_NE_BANG		6
#define RELOP_UNKNOWN	7

const static unsigned char highlow_tab[] PROGMEM = { 
  'H','I','G','H'+0x80,
  'H','I'+0x80,
  'L','O','W'+0x80,
  'L','O'+0x80,
  0
};
#define HIGHLOW_HIGH    1
#define HIGHLOW_UNKNOWN 4

#define STACK_SIZE (sizeof(struct stack_for_frame)*5)
#define VAR_SIZE sizeof(short int) // Size of variables in bytes

static unsigned char *stack_limit;
static unsigned char *program_start;
static unsigned char *program_end;
static unsigned char *stack; // Software stack for things that should go on the CPU stack
static unsigned char *variables_begin;
static unsigned char *current_line;
static unsigned char *sp;
#define STACK_GOSUB_FLAG 'G'
#define STACK_FOR_FLAG 'F'
static unsigned char table_index;
static LINENUM linenum;

static const unsigned char okmsg[]            PROGMEM = "OK";
static const unsigned char whatmsg[]          PROGMEM = "What? ";
static const unsigned char howmsg[]           PROGMEM =	"How?";
static const unsigned char sorrymsg[]         PROGMEM = "Sorry!";
static const unsigned char initmsg[]          PROGMEM = "TinyBasic Plus " kVersion;
static const unsigned char memorymsg[]        PROGMEM = " bytes free.";
#ifdef ARDUINO
#ifdef ENABLE_EEPROM
static const unsigned char eeprommsg[]        PROGMEM = " EEProm bytes total.";
static const unsigned char eepromamsg[]       PROGMEM = " EEProm bytes available.";
#endif
#endif
static const unsigned char breakmsg[]         PROGMEM = "break!";
static const unsigned char unimplimentedmsg[] PROGMEM = "Unimplemented";
static const unsigned char backspacemsg[]     PROGMEM = "\b \b";
static const unsigned char indentmsg[]        PROGMEM = "    ";
static const unsigned char sderrormsg[]       PROGMEM = "SD card error.";
static const unsigned char sdfilemsg[]        PROGMEM = "SD file error.";
static const unsigned char dirextmsg[]        PROGMEM = "(dir)";
static const unsigned char slashmsg[]         PROGMEM = "/";
static const unsigned char spacemsg[]         PROGMEM = " ";

static int inchar(void);
static void outchar(unsigned char c);
static void line_terminator(void);
static short int expression(void);
static unsigned char breakcheck(void);
/***************************************************************************/
static void ignore_blanks(void)
{
  while(*txtpos == SPACE || *txtpos == TAB)
    txtpos++;
}


/***************************************************************************/
static void scantable(const unsigned char *table)
{
  int i = 0;
  table_index = 0;
  while(1)
  {
    // Run out of table entries?
    if(pgm_read_byte( table ) == 0)
      return;

    // Do we match this character?
    if(txtpos[i] == pgm_read_byte( table ))
    {
      i++;
      table++;
    }
    else
    {
      // do we match the last character of keywork (with 0x80 added)? If so, return
      if(txtpos[i]+0x80 == pgm_read_byte( table ))
      {
        txtpos += i+1;  // Advance the pointer to following the keyword
        ignore_blanks();
        return;
      }

      // Forward to the end of this keyword
      while((pgm_read_byte( table ) & 0x80) == 0)
        table++;

      // Now move on to the first character of the next word, and reset the position index
      table++;
      table_index++;
      ignore_blanks();
      i = 0;
    }
  }
}

/***************************************************************************/
static void pushb(unsigned char b)
{
  sp--;
  *sp = b;
}

/***************************************************************************/
static unsigned char popb()
{
  unsigned char b;
  b = *sp;
  sp++;
  return b;
}

/***************************************************************************/
void printnum(int num)
{
  int digits = 0;

  if(num < 0)
  {
    num = -num;
    outchar('-');
  }
  do {
    pushb(num%10+'0');
    num = num/10;
    digits++;
  }
  while (num > 0);

  while(digits > 0)
  {
    outchar(popb());
    digits--;
  }
}

void printUnum(unsigned int num)
{
  int digits = 0;

  do {
    pushb(num%10+'0');
    num = num/10;
    digits++;
  }
  while (num > 0);

  while(digits > 0)
  {
    outchar(popb());
    digits--;
  }
}

/***************************************************************************/
static unsigned short testnum(void)
{
  unsigned short num = 0;
  ignore_blanks();

  while(*txtpos>= '0' && *txtpos <= '9' )
  {
    // Trap overflows
    if(num >= 0xFFFF/10)
    {
      num = 0xFFFF;
      break;
    }

    num = num *10 + *txtpos - '0';
    txtpos++;
  }
  return	num;
}
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
void loop()
{
  Serial.println("&with &V&G&A&x&& video output"); 
  //Serial.println("Version beta 1.0"); 
  unsigned char *start;
  unsigned char *newEnd;
  unsigned char linelen;
  boolean isDigital;
  boolean alsoWait = false;
  int val;

#ifdef ARDUINO
#ifdef ENABLE_TONES
  noTone( kPiezoPin );
#endif
#endif

  program_start = program;
  program_end = program_start;
  sp = program+sizeof(program);  // Needed for printnum
  stack_limit = program+sizeof(program)-STACK_SIZE;
  variables_begin = stack_limit - 27*VAR_SIZE;

  // memory free
  printnum(variables_begin-program_end);
  printmsg(memorymsg);
#ifdef ARDUINO
#ifdef ENABLE_EEPROM
  // eprom size
  printnum( E2END+1 );
  printmsg( eeprommsg );
#endif /* ENABLE_EEPROM */
#endif /* ARDUINO */

warmstart:
  // this signifies that it is running in 'direct' mode.
  current_line = 0;
  sp = program+sizeof(program);
  printmsg(okmsg);

prompt:
  if( triggerRun ){
    triggerRun = false;
    current_line = program_start;
    goto execline;
  }

  getln( '>' );
  toUppercaseBuffer();

  txtpos = program_end+sizeof(unsigned short);

  // Find the end of the freshly entered line
  while(*txtpos != NL)
    txtpos++;

  // Move it to the end of program_memory
  {
    unsigned char *dest;
    dest = variables_begin-1;
    while(1)
    {
      *dest = *txtpos;
      if(txtpos == program_end+sizeof(unsigned short))
        break;
      dest--;
      txtpos--;
    }
    txtpos = dest;
  }

  // Now see if we have a line number
  linenum = testnum();
  ignore_blanks();
  if(linenum == 0)
    goto direct;

  if(linenum == 0xFFFF)
    goto qhow;

  // Find the length of what is left, including the (yet-to-be-populated) line header
  linelen = 0;
  while(txtpos[linelen] != NL)
    linelen++;
  linelen++; // Include the NL in the line length
  linelen += sizeof(unsigned short)+sizeof(char); // Add space for the line number and line length

  // Now we have the number, add the line header.
  txtpos -= 3;
  *((unsigned short *)txtpos) = linenum;
  txtpos[sizeof(LINENUM)] = linelen;


  // Merge it into the rest of the program
  start = findline();

  // If a line with that number exists, then remove it
  if(start != program_end && *((LINENUM *)start) == linenum)
  {
    unsigned char *dest, *from;
    unsigned tomove;

    from = start + start[sizeof(LINENUM)];
    dest = start;

    tomove = program_end - from;
    while( tomove > 0)
    {
      *dest = *from;
      from++;
      dest++;
      tomove--;
    }	
    program_end = dest;
  }

  if(txtpos[sizeof(LINENUM)+sizeof(char)] == NL) // If the line has no txt, it was just a delete
    goto prompt;



  // Make room for the new line, either all in one hit or lots of little shuffles
  while(linelen > 0)
  {	
    unsigned int tomove;
    unsigned char *from,*dest;
    unsigned int space_to_make;

    space_to_make = txtpos - program_end;

    if(space_to_make > linelen)
      space_to_make = linelen;
    newEnd = program_end+space_to_make;
    tomove = program_end - start;


    // Source and destination - as these areas may overlap we need to move bottom up
    from = program_end;
    dest = newEnd;
    while(tomove > 0)
    {
      from--;
      dest--;
      *dest = *from;
      tomove--;
    }

    // Copy over the bytes into the new space
    for(tomove = 0; tomove < space_to_make; tomove++)
    {
      *start = *txtpos;
      txtpos++;
      start++;
      linelen--;
    }
    program_end = newEnd;
  }
  goto prompt;

unimplemented:
  printmsg(unimplimentedmsg);
  goto prompt;

qhow:	
  printmsg(howmsg);
  goto prompt;

qwhat:	
  printmsgNoNL(whatmsg);
  if(current_line != NULL)
  {
    unsigned char tmp = *txtpos;
    if(*txtpos != NL)
      *txtpos = '^';
    list_line = current_line;
    printline();
    *txtpos = tmp;
  }
  line_terminator();
  goto prompt;

qsorry:	
  printmsg(sorrymsg);
  goto warmstart;

run_next_statement:
  while(*txtpos == ':')
    txtpos++;
  ignore_blanks();
  if(*txtpos == NL)
    goto execnextline;
  goto interperateAtTxtpos;

direct: 
  txtpos = program_end+sizeof(LINENUM);
  if(*txtpos == NL)
    goto prompt;

interperateAtTxtpos:
  if(breakcheck())
  {
    printmsg(breakmsg);
    goto warmstart;
  }

  scantable(keywords);

  switch(table_index)
  {
  case KW_DELAY:
    {
#ifdef ARDUINO
      expression_error = 0;
      val = expression();
      delay( val );
      goto execnextline;
#else
      goto unimplemented;
#endif
    }

  case KW_FILES:
    goto files;
  case KW_LIST:
    goto list;
  case KW_CHAIN:
    goto chain;
  case KW_LOAD:
    goto load;
  case KW_MEM:
    goto mem;
  case KW_NEW:
    if(txtpos[0] != NL)
      goto qwhat;
    program_end = program_start;
    goto prompt;
  case KW_RUN:
    current_line = program_start;
    goto execline;
  case KW_SAVE:
    goto save;
  case KW_NEXT:
    goto next;
  case KW_LET:
    goto assignment;
  case KW_IF:
    short int val;
    expression_error = 0;
    val = expression();
    if(expression_error || *txtpos == NL)
      goto qhow;
    if(val != 0)
      goto interperateAtTxtpos;
    goto execnextline;

  case KW_GOTO:
    expression_error = 0;
    linenum = expression();
    if(expression_error || *txtpos != NL)
      goto qhow;
    current_line = findline();
    goto execline;

  case KW_GOSUB:
    goto gosub;
  case KW_RETURN:
    goto gosub_return; 
  case KW_REM:
  case KW_QUOTE:
    goto execnextline;	// Ignore line completely
  case KW_FOR:
    goto forloop; 
  case KW_INPUT:
    goto input; 
  case KW_PRINT:
  case KW_QMARK:
    goto print;
  case KW_POKE:
    goto poke;
  case KW_END:
  case KW_STOP:
    // This is the easy way to end - set the current line to the end of program attempt to run it
    if(txtpos[0] != NL)
      goto qwhat;
    current_line = program_end;
    goto execline;
  case KW_BYE:
    // Leave the basic interperater
    return;

  case KW_AWRITE:  // AWRITE <pin>, HIGH|LOW
    isDigital = false;
    goto awrite;
  case KW_DWRITE:  // DWRITE <pin>, HIGH|LOW
    isDigital = true;
    goto dwrite;

  case KW_RSEED:
    goto rseed;

#ifdef ENABLE_TONES
  case KW_TONEW:
    alsoWait = true;
  case KW_TONE:
    goto tonegen;
  case KW_NOTONE:
    goto tonestop;
#endif

#ifdef ARDUINO
#ifdef ENABLE_EEPROM
  case KW_EFORMAT:
    goto eformat;
  case KW_ESAVE:
    goto esave;
  case KW_ELOAD:
    goto eload;
  case KW_ELIST:
    goto elist;
  case KW_ECHAIN:
    goto echain;
#endif
#endif

  case KW_DEFAULT:
    goto assignment;
  default:
    break;
  }

execnextline:
  if(current_line == NULL)		// Processing direct commands?
    goto prompt;
  current_line +=	 current_line[sizeof(LINENUM)];

execline:
  if(current_line == program_end) // Out of lines to run
    goto warmstart;
  txtpos = current_line+sizeof(LINENUM)+sizeof(char);
  goto interperateAtTxtpos;

#ifdef ARDUINO
#ifdef ENABLE_EEPROM
elist:
  {
    int i;
    for( i = 0 ; i < (E2END +1) ; i++ )
    {
      val = EEPROM.read( i );

      if( val == '\0' ) {
        goto execnextline;
      }

      if( ((val < ' ') || (val  > '~')) && (val != NL) && (val != CR))  {
        outchar( '?' );
      } 
      else {
        outchar( val );
      }
    }
  }
  goto execnextline;

eformat:
  {
    for( int i = 0 ; i < E2END ; i++ )
    {
      if( (i & 0x03f) == 0x20 ) outchar( '.' );
      EEPROM.write( i, 0 );
    }
    outchar( LF );
  }
  goto execnextline;

esave:
  {
    outStream = kStreamEEProm;
    eepos = 0;

    // copied from "List"
    list_line = findline();
    while(list_line != program_end) {
      printline();
    }
    outchar('\0');

    // go back to standard output, close the file
    outStream = kStreamSerial;
    
    goto warmstart;
  }
  
  
echain:
  runAfterLoad = true;

eload:
  // clear the program
  program_end = program_start;

  // load from a file into memory
  eepos = 0;
  inStream = kStreamEEProm;
  inhibitOutput = true;
  goto warmstart;
#endif /* ENABLE_EEPROM */
#endif

input:
  {
    unsigned char var;
    int value;
    ignore_blanks();
    if(*txtpos < 'A' || *txtpos > 'Z')
      goto qwhat;
    var = *txtpos;
    txtpos++;
    ignore_blanks();
    if(*txtpos != NL && *txtpos != ':')
      goto qwhat;
inputagain:
    tmptxtpos = txtpos;
    getln( '?' );
    toUppercaseBuffer();
    txtpos = program_end+sizeof(unsigned short);
    ignore_blanks();
    expression_error = 0;
    value = expression();
    if(expression_error)
      goto inputagain;
    ((short int *)variables_begin)[var-'A'] = value;
    txtpos = tmptxtpos;

    goto run_next_statement;
  }
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

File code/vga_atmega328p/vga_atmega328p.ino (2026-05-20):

/******************************************************************* 
*                Arduino TinyBasic VGA PC                          * 
*                                                                  *
*  Version 1 - February the 4th, 2018, Written by Roberto Melzi    * 
*                                                                  *
*  Arduino TinyBasic VGA PC is a simpe, 8-bit retro-PC, composed   * 
*  by two Arduino board. One runs TinyBasic and the PS2 library,   * 
*  while the other runs a code, based on the VGAx library, to      * 
*  generate the output signal for a VGA monitor.                   *
*                                                                  *
*  Both TinyBasic and VGAx requires Arduino IDE version 1.6.4      * 
*  VGAx library does not work for newer or elder software          *
*  versions.                                                       * 
*                                                                  *
*  VGAx Library written By Sandro Maffiodo aka Smaffer.            * 
*  https://github.com/smaffer/vgax                                 * 
*  See also the Arduino forum:                                     * 
*  http://forum.arduino.cc/index.php?topic=328631.0                * 
*  and on Instructables:                                           *
*  http://www.instructables.com/member/Rob%20Cai/instructables/    *
*                                                                  * 
*******************************************************************/ 

#include <VGAX.h>
//#include <math.h>
#define FNT_NANOFONT_HEIGHT 6
#define FNT_NANOFONT_SYMBOLS_COUNT 95
//#include <VGAXUtils.h>

VGAX vga;
//VGAXUtils vgaU;

//data size=570 bytes
const unsigned char fnt_nanofont_data[FNT_NANOFONT_SYMBOLS_COUNT][1+FNT_NANOFONT_HEIGHT] PROGMEM={
{ 3, 32, 32, 32, 0, 32, 0, }, //glyph '!' code=0
{ 4, 80, 80, 0, 0, 0, 0, }, //glyph '"' code=1
{ 5, 80, 248, 80, 248, 80, 0, },  //glyph '#' code=2-
{ 5, 120, 160, 112, 40, 240, 0, },  //glyph '$' code=3
{ 5, 136, 16, 32, 64, 136, 0, },  //glyph '%' code=4
{ 5, 96, 144, 104, 144, 104, 0, },  //glyph '&' code=5
{ 2, 32, 64, 0, 0, 0, 0, },  //glyph ''' code=6
{ 2, 64, 128, 128, 128, 64, 0, }, //glyph '(' code=7
{ 2, 128, 64, 64, 64, 128, 0, },  //glyph ')' code=8
{ 4, 0, 80, 32, 80, 0, 0, },  //glyph '*' code=9
{ 4, 0, 32, 112, 32, 0, 0, }, //glyph '+' code=10
{ 2, 0, 0, 0, 0, 32, 64, },  //glyph ',' code=11
{ 4, 0, 0, 112, 0, 0, 0, }, //glyph '-' code=12
{ 2, 0, 0, 0, 0, 64, 0, }, //glyph '.' code=13
{ 5, 8, 16, 32, 64, 128, 0, },  //glyph '/' code=14
//{ 4, 96, 144, 144, 144, 96, 0, }, //glyph '0' code=15
{ 4, 96, 176, 144, 208, 96, 0, }, //glyph '0' code=15
{ 4, 32, 96, 32, 32, 112, 0, },  //glyph '1' code=16
{ 4, 224, 16, 96, 128, 240, 0, }, //glyph '2' code=17
{ 4, 224, 16, 96, 16, 224, 0, },  //glyph '3' code=18
{ 4, 144, 144, 240, 16, 16, 0, }, //glyph '4' code=19
{ 4, 240, 128, 224, 16, 224, 0, },  //glyph '5' code=20
{ 4, 96, 128, 224, 144, 96, 0, }, //glyph '6' code=21
{ 4, 240, 16, 32, 64, 64, 0, }, //glyph '7' code=22
{ 4, 96, 144, 96, 144, 96, 0, },  //glyph '8' code=23
{ 4, 96, 144, 112, 16, 96, 0, },  //glyph '9' code=24
{ 3, 0, 32, 0, 32, 0, 0, }, //glyph ':' code=25
{ 2, 0, 32, 0, 32, 64, 0, },  //glyph ';' code=26 
{ 4, 16, 32, 64, 32, 16, 0, }, //glyph '<' code=27
{ 4, 0, 112, 0, 112, 0, 0, }, //glyph '=' code=28
{ 4, 64, 32, 16, 32, 64, 0, },  //glyph '>' code=29
{ 4, 224, 16, 96, 0, 64, 0, },  //glyph '?' code=30
{ 4, 96, 144, 176, 128, 112, 0, },  //glyph '@' code=31
{ 4, 96, 144, 240, 144, 144, 0, },  //glyph 'A' code=32
{ 4, 224, 144, 224, 144, 224, 0, }, //glyph 'B' code=33
{ 4, 112, 128, 128, 128, 112, 0, }, //glyph 'C' code=34
{ 4, 224, 144, 144, 144, 224, 0, }, //glyph 'D' code=35
{ 4, 240, 128, 224, 128, 240, 0, }, //glyph 'E' code=36
{ 4, 240, 128, 224, 128, 128, 0, }, //glyph 'F' code=37
{ 4, 112, 128, 176, 144, 112, 0, }, //glyph 'G' code=38
{ 4, 144, 144, 240, 144, 144, 0, }, //glyph 'H' code=39
{ 4, 112, 32, 32, 32, 112, 0, },  //glyph 'I' code=40
{ 4, 240, 16, 16, 144, 96, 0, },  //glyph 'J' code=41
{ 4, 144, 160, 192, 160, 144, 0, }, //glyph 'K' code=42
{ 4, 128, 128, 128, 128, 240, 0, }, //glyph 'L' code=43
{ 5, 136, 216, 168, 136, 136, 0, }, //glyph 'M' code=44
{ 4, 144, 208, 176, 144, 144, 0, }, //glyph 'N' code=45
{ 4, 96, 144, 144, 144, 96, 0, }, //glyph 'O' code=46
{ 4, 224, 144, 224, 128, 128, 0, }, //glyph 'P' code=47
{ 4, 96, 144, 144, 144, 96, 16, },  //glyph 'Q' code=48
{ 4, 224, 144, 224, 160, 144, 0, }, //glyph 'R' code=49
{ 4, 112, 128, 96, 16, 224, 0, }, //glyph 'S' code=50
{ 4, 112, 32, 32, 32, 32, 0, }, //glyph 'T' code=51
{ 4, 144, 144, 144, 144, 96, 0, },  //glyph 'U' code=52
{ 4, 80, 80, 80, 80, 32, 0, },  //glyph 'V' code=53
{ 5, 136, 168, 168, 168, 80, 0, },  //glyph 'W' code=54
{ 4, 144, 144, 96, 144, 144, 0, },  //glyph 'X' code=55
{ 4, 80, 80, 32, 32, 32, 0, },  //glyph 'Y' code=56
{ 4, 240, 16, 96, 128, 240, 0, }, //glyph 'Z' code=57
{ 3, 96, 64, 64, 64, 96, 0, }, //glyph '[' code=58
{ 5, 128, 64, 32, 16, 8, 0, },  //glyph '\' code=59
{ 3, 96, 32, 32, 32, 96, 0, },  //glyph ']' code=60
{ 5, 32, 80, 136, 0, 0, 0, }, //glyph '^' code=61
{ 4, 0, 0, 0, 0, 240, 0, }, //glyph '_' code=62
//{ 2, 128, 64, 0, 0, 0, 0, },  //glyph '`' code=63
{ 3, 64, 32, 0, 0, 0, 0, },  //glyph '`' code=63
{ 4, 0, 112, 16, 112, 112, 0, },  //glyph 'a' code=64
{ 4, 64, 112, 80, 80, 112, 0, }, //glyph 'b' code=65
{ 4, 0, 112, 64, 64, 112, 0, }, //glyph 'c' code=66
{ 4, 16, 112, 80, 80, 112, 0, },  //glyph 'd' code=67
{ 3, 0, 112, 112, 64, 112, 0, }, //glyph 'e' code=68
{ 3, 32, 64, 96, 64, 64, 0, },  //glyph 'f' code=69
{ 4, 0, 112, 80, 112, 16, 112, },  //glyph 'g' code=70
{ 3, 64, 114, 80, 80, 80, 0, }, //glyph 'h' code=71
{ 2, 32, 0, 32, 32, 32, 0, }, //glyph 'i' code=72
{ 3, 0, 96, 32, 32, 32, 64, },  //glyph 'j' code=73
{ 4, 64, 80, 96, 80, 80, 0, }, //glyph 'k' code=74
{ 3, 32, 32, 32, 32, 32, 0, }, //glyph 'l' code=75
{ 5, 0, 248, 168, 168, 168, 0, }, //glyph 'm' code=76
{ 3, 0, 112, 80, 80, 80, 0, }, //glyph 'n' code=77
{ 4, 0, 112, 80, 80, 112, 0, }, //glyph 'o' code=78
{ 4, 0, 112, 80, 80, 112, 64, }, //glyph 'p' code=79
{ 4, 0, 112, 80, 80, 112, 16, },  //glyph 'q' code=80
{ 4, 0, 112, 64, 64, 64, 0, }, //glyph 'r' code=81
{ 3, 0, 96, 64, 32, 96, 0, },  //glyph 's' code=82
{ 4, 32, 112, 32, 32, 32, 0, }, //glyph 't' code=83
{ 4, 0, 80, 80, 80, 112, 0, }, //glyph 'u' code=84
{ 4, 0, 80, 80, 80, 32, 0, },  //glyph 'v' code=85
{ 5, 0, 168, 168, 168, 80, 0, },  //glyph 'w' code=86
{ 3, 0, 80, 32, 80, 80, 0, },  //glyph 'x' code=87
{ 4, 0, 80, 80, 112, 16, 112, },  //glyph 'y' code=88
{ 3, 0, 96, 32, 64, 96, 0, },  //glyph 'z' code=89
{ 4, 48, 32, 96, 32, 48, 0, }, //glyph '{' code=90
{ 3, 32, 32, 32, 32, 32, 0, }, //glyph '|' code=91
{ 4, 96, 32, 48, 32, 96, 0, },  //glyph '}' code=92
{ 5, 248, 248, 248, 248, 248, 248, },  //glyph '~' code=93 - full character used for deleting 
{ 4, 48, 64, 224, 64, 240, 0, },  //glyph 'Â£' code=94 
};
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

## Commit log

2026-05-15 [feat] adding KICAD project and Gerber files
    [Projekt_Schaltplan-B_Cu.gbr, Projekt_Schaltplan-B_Mask.gbr, Projekt_Schaltplan-B_Paste.gbr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]
2026-05-15 [refactoring, feat] adding documentation and refactoring pcb annotation
    [Projekt_Schaltplan.kicad_sch]
2026-05-19 [refactor] refactoring repo
    [Projekt_Schaltplan-B_Cu.gbr, Projekt_Schaltplan-B_Mask.gbr, Projekt_Schaltplan-B_Paste.gbr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]
2026-05-19 [feat] adding vga-driver for atmega328p #1
2026-05-20 [feat] adding render of pcb for visual representation
